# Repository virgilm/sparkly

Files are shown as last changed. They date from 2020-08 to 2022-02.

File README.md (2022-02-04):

# sparkly
**Swimming-Pool Automation Systen with Raspberry Pi + Home Assistant**

#### Disclaimer: THIS IS VERY MUCH A WORK IN PROGRESS, DO NOT EXPECT TO CLONE THIS AND HAVE A WORKING SYSTEM JUST YET!!!



## Overview:

 A cost-effective, easy-to-build, easy-to-use "Swimming Pool Automation System" with top functions to automate, control and monitor (from web) small-medium size swimming pools.

- Automatic filter control (single speed pumps) based on turnover, temperature and energy tariffs. Manual scheduling too. The power relay used needs to be able to withstand the Inductive Load of the Pool Pump motor. 
- 3 sensors:
  - tentacle ([whitebox T3](https://atlas-scientific.com/electrical-isolation/whitebox-t3/)) carrier board with
  - [ph](https://www.atlas-scientific.com/product_pages/circuits/ezo_ph.html), [orp](https://www.atlas-scientific.com/product_pages/circuits/ezo_orp.html), and [RTD](https://atlas-scientific.com/embedded-solutions/ezo-rtd-temperature-circuit/). A custom I2C sensor for HA has been developed.
- and [8 relays](https://sequentmicrosystems.com/collections/home-automation/products/raspberry-pi-relays-stackable-card) (custom HA component for sequent 8 board relay). The relays control :
  - pump on/off
  - muriatic acid injection (to regulate pH)
  - bleach injection (to mantain sanitization level) **or** salt chlorinator control

 The system is intended to monitor and *"automagically"* control most important pool functions and notify to mobile all possible events requiring attention.

 Integrated Node Red for advanced automation functionality.
 
 ## Build system (slightly out of date)
 
 Follow instructions in wiki [howto build a bypass to connect sensors to the pool](https://github.com/segalion/raspipool/wiki/Bypass-for-sensors), [howto connect sensors to the raspberry pi](https://github.com/segalion/raspipool/wiki/Sensors-connection-(DS18B20,-and-EZO-pH-and-ORP)) and [howto connect relays between pumps and raspberry pi](https://github.com/segalion/raspipool/wiki/Connection-of-relays-for-pump-control)
 
 ## Install (really needs work!!! - contributions appreciated)
 0. Install [HAOS](https://www.home-assistant.io/installation/raspberrypi#install-home-assistant-operating-system) in a raspberry pi (3 or 4), and setup wifi connection. (If an advanced user, you can instead install [raspberry pi OS](https://www.raspberrypi.com/software/) + [Home Assistant Core](https://www.home-assistant.io/installation/raspberrypi#install-home-assistant-core))
 *PLEASE DO NOT ASK FOR ASSISTANCE IN INSTALLING HA. It is an overly, unnnecesarly complicated process that should be fully suported by HA.*
 1. Install Node-Red
 2. Copy/clone this repository in the homeassistant conf_dir ( i.e. /home/homeassistant/.homeassistant/ or /mnt/data/supervisor/homeassistant/). The following form allows you to initialize a non-empty directory:

    `git init .`

    `git remote add origin <repository-url>`

    `git pull origin master`

 3. Create a 'secrets.yaml' file under the config_dir directory, containing:

    `latitude: <latitude>`

    `longitude: <longitude>`
    
    `openweathermap_api_key: <key>`
    
    `pushbullet_api_key: <key>`

 4. Start HA and access [http://<sparkly.local>:8123](http://sparkly.local:8123)
 5. Because HA is so wise, you'll need to enable the following integrations via UI (TODO: is there a way to fix this?):
   - Scheduler
   - OpenWeatherMap (you'll need to supply your API key, even if you already set it in your secrets file above)
 6. Change your HA panel configuration to point to your NR installation (check panel_iframe in configuration.yaml) (NR runs at [http://<sparkly.local>:46836](http://sparkly.local:46836))
 7. Connect your node red installation to HA.
 - Generate a [long lived token](https://www.atomicha.com/home-assistant-how-to-generate-long-lived-access-token-part-1/).
 - [Configure HA](https://leonardosmarthomemakers.com/how-to-install-node-red-on-a-raspberry-for-your-home-assistant-smart-home/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) node in Node Red UI

 ## TODO:
 - Water temperature (1-wire [DS18B20 waterproof](https://aliexpress.com/item/32968031204.html))
 - SWC – Salt Water Chlorinator (instead of bleach injections) - in progress
 - Improve calibration (3-point for pH)
 - Heater control
 - Correction of FC-ORP based on CYA (actually only linear correction)
 - Control Variable Speed Motor via RS485
 - Two speed pumps (re-add support)
  
<sub> This is a fork of [raspipool](https://github.com/huehueteotl/raspipool) HEAVILY modified. Thanks to segalion for the original work. Thanks to Hidromaster, Piscidoc, and all DIY enthusiasts from [hablemosdepisicnas](http://www.hablemosdepiscinas.com/foro/viewtopic.php?f=11&t=3906) and [TFP](https://www.troublefreepool.com/threads/raspipool-pool-automation-system-with-raspberry-pi-home-assistant.188410/) forums.</sub>

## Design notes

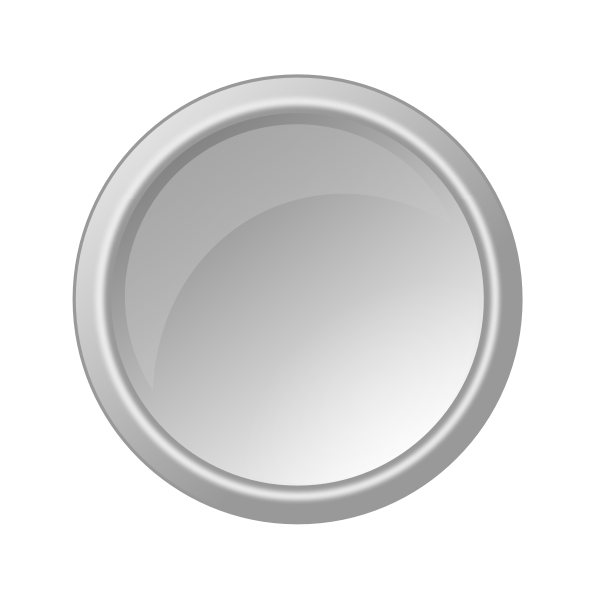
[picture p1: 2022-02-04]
www/glossy-lightgray-button.png

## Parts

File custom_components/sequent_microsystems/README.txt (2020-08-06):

Very basic code to support this board in HA:
https://sequentmicrosystems.com/index.php?route=product/product&product_id=50

Doc explaining the dev process in HA:
https://developers.home-assistant.io/docs/development_index

TODO:
- test I2C communication on init, fail if not working
- implement port logic
- lib8relay 1.0.0 needs to be pushed to PyPi!!
https://developers.home-assistant.io/docs/creating_component_code_review/#4-communication-with-devicesservices
https://jeffknupp.com/blog/2013/08/16/open-sourcing-a-python-project-the-right-way/
Meanwhile, to use it in dev:
https://developers.home-assistant.io/docs/creating_integration_manifest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
- extend this to other devices/input devices too. I can help.

References:
- good example:
https://github.com/home-assistant/core/tree/dev/homeassistant/components/raspihats
- the end result should live here:
https://github.com/home-assistant/core/tree/dev/homeassistant/components

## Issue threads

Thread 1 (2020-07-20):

Issue with flow template

virgilm, 2020-07-20:
Curious if this happens to other people too.

Hass logs:
> 020-07-19 22:01:32 ERROR (MainThread) [homeassistant.components.template.sensor] Could not render template Remain cycles: UndefinedError: 'str object' has no attribute 'minute'

This seems to be because the following line in flow.yaml:
>           {% set nextcycle = strptime(states('sensor.cycle_pool'),'%H:%M').hour + strptime(states('sensor.cycle_pool'),'%H:%M').minute|int/60 %}

sensor.cycle_pool seems to be a string and not a date, or the template seems to think so. It seems that strptime implementation is broken honestly.

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

This seems similar to:
https://community.home-assistant.io/t/convert-string-to-time/37303/2

Closed 2020-07-21.

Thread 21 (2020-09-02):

enity in non-numeric error

AhmedElsafi, 2020-09-02:
Hello,
I am trying to run the raspipool application. I am getting a message for entity is non-numeric for the ph,orp and the pool temperature.   I wonder if you could help me with that
Regards,

virgilm, 2020-09-02:
Did you build the hardware according to the diagrams? Those errors in general indicate you are not getting any readings from your sensors. If you did, check with the command line python shell provided by Atlas Scientific that all your sensors are working in I2C mode and reading data.

docsparks, 2020-09-10:
i had this issue with segalions atlas code and found that i didn't configure my ec probe to give me a reading with a decimal or comma and the code wasn't able to handle it.   forgot which line in the code it was but that was it.

AhmedElsafi, 2020-09-14:
Thanks for the response. Will try that.

AhmedElsafi, 2020-10-19:
Thanks. I went back to it and did the configuration to I2C.

I have another question for you have an early rev that is based on one- wire temperature sensor.

I followed the original BOM

AhmedElsafi, 2020-10-19:
Thanks

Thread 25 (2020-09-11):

calibration only for i2c devices?

docsparks, 2020-09-11:
it looks like the Calibration code is only fitted for i2c device mode,  I'm still new to python and GitHub.   you've updated segalions atlas code quite a bit.   any chances to help me improve calibration for sensors on serialport via USB atlas ezo device? thank you

virgilm, 2020-09-11:
My sensors are I2C, I can't even connect them via serial, as I don't have a carrier board. Calibration clearly needs some work. If you want to give it a try, all you need to do is replace the I2C commands with equivalent serial commands, the logic still stands. You can find those [here](https://atlas-scientific.com/files/oem_pH_datasheet.pdf); serial calibration starts at page 19. pH is the trickiest one, my code only does midpoint calibration for now.

docsparks, 2020-09-15:
Sorry for the delay.    My issue isnt so much the process of calibration, as much as it is creating commands within the python script.    I have already used my sensors for a length of time within windows and understand the commands to do different things, my setback here is my lack of python programming context and homeassistants abilities..

I see that the atlas integration already does mostly what I want, if i wanted to for example, change the temperature for the ph probe, id have to send a command including the current water temperature to the atlas ph sensor via the integration.

but the integration only creates a sensor and has the sensor value as its only return to the component.

how would i extend the existing python script to allow the temperature be set?

I imagine (using hassio/homeassistant OS on a rpi) that i cant open access to the usb port thats already in use by the atlas component, from a custom python script?  or can i?  ill make an attempt at coding this myself today but im still sure that some changes to the origin sensor.py can be fitted to allow input commands, ie set temperature of water.

any help is appreciated, thanks!

virgilm, 2020-09-15:
Oh, I understand. I'm quite new to HA too, I don't know of a way to modify a sensor in such a way - maybe there is one. I'm sure we could implement some other HA entity (e.g. check https://developers.home-assistant.io/docs/dev_101_services) to perform some output functions. The sample code [here](https://www.atlas-scientific.com/files/pi_sample_code.pdf) has an example of python with UART mode.

docsparks, 2020-09-16:
After spending the day yesterday attempting to learn what I could, this is where i got..

segalion had originally started trying to make the code allow parameters for settings, via service.  Found in
https://github.com/segalion/raspipool/blob/master/custom_components/atlas_scientific/__init__.py

I went through numerous custom components I have, as well as info from https://developers.home-assistant.io/docs/dev_101_services and for the limited time i had yesterday, couldnt get anywhere.

I have yet to fully follow the instructions set out with the custom service docs but I still have yet to see in other custom components how the service code could even interact with the python coding in the sensor.py.

I dont have any knowledge with python but have years of programming experience in .net and some java.  I may post on the homeassistant forums.

I hope this helps you make any progress

virgilm, 2020-09-16:
Sorry, I'm not going to spend time on this, as I don't even have a way to test this out, but the only way I can think of at least at this point would be to have a separate entity (not the sensor) that could run the calibration. From what I can gather, extending a sensor does not have a way to add a 'calibrate' method to it. You could do something similar to what I did, which is to run a shell script (scripts.yaml), which in turn calls a python routine. Unfortunately, the python scripts in HA are quite useless from my perspective, as no imports are allowed: https://www.home-assistant.io/integrations/python_script/

docsparks, 2020-09-16:
Thanks again for your contributions to the original code.   It does help.  I have linked to your repo in my question on the home assistant forums.
[https://community.home-assistant.io/t/adding-input-parameters-to-a-custom-component-that-is-only-a-sensor/227281](url)

danielegger1, 2022-01-30:
Not sure where the best place is to contact you, but this might be ok, have you had any luck at implementing the Ezo Pumps with I2C?
Tentacle T3 works without issues?
Bit afraid before buying everything
Thanks in advance

virgilm, 2022-01-30:
T3 works without any issues (but it's a bit expensive for what it is). I have a pump too, but I did not try it out yet. I see no reason for it not to work as expected. I have a bunch of code written for this project, I will push it when I get a chance... way too many things to do, and my pump is an industrial 240V one right now. It should be a matter of just adding to the custom component and adding a switch.

danielegger1, 2022-01-31:
Thanks for your fast reply :)
i just figured out that going through the wifi kit https://www.robesol.nl/en/wi-fi-pool-kit-bare-bones.html might be the easiest way
But I can try Raspipool with that also, just need to manually wire it instead of going through Tentacle.
What do you think about that unit?
Really looking forward to your updated code, I am always happy that people like you are sharing their hard work for stupid users like me :)

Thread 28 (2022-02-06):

GREAT WORK

bbombek, 2022-02-06:
So I have struggled with this build for one year. It seems to be very hard....
And HA is constantly changing. Now the new version doesnt support UART?? Is that a problem?
Anyway i am again stuck.
I see that
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

Also the readme i got stuck at

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

I dont know how how to do no. 6 and 7.
and also i got now two red nodes??

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

And I still dont get any readings from EZo circuits. I Dont know how to enable i2C mode....
and also
what is this?
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

what is sparkly local i dont understans??
PLEASE HELP

virgilm, 2022-02-06:
To set EZO sensors to I2C mode, you can follow [this](https://www.instructables.com/UART-AND-I2C-MODE-SWITCHING-FOR-ATLAS-SCIENTIFIC-E/) tutorial. My version does not support UART mode, you would have to make it work if you really wanted to (the code is there, but commented out). I highly recommend using I2C mode though, it is easier to use and more reliable.

HA is indeed constantly changing (and not for the better IMO). I assume you installed the supervised version of HA, seeing the screenshots - and that is OK. Steps 6 & 7 are irrelevant to you, NR is running and connected to HA apparently, and the second NR entry is useless - just ignore it or remove it from your configuration file.

As I mentioned in the readme, the installation is very much a work in progress and I use HA Core, where some if this stuff is more complicated - but it runs much better on my RPi Zero W 2. I'm actually happy you made it that far, if you can contribute back with Install steps for HA Supervised, that would be nice.

Finally, my installation is called sparkly.local instead of homeassistant.local, so you already have that last point (Start HA and access) working :)

bbombek, 2022-02-06:
OK KUULL
Getting there!
So I enabled I2C mode manually on the EZO circuits now there is the Blue Light!
But still no communication with raspberry pi.
I know how to do it in raspbian OS
https://files.atlas-scientific.com/pi_sample_code.pdf
But how to do that in HA OS??
I found this should i do it?
https://www.home-assistant.io/common-tasks/os/#enable-i2c
I will gladly make a tutorial if I am Successful!

bbombek, 2022-02-06:
So I did this also..
https://www.home-assistant.io/common-tasks/os/#enable-i2c-via-home-assistant-operating-system-terminal
And nothing from the pH sensor...
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

Should sensors still be connected as segalion did??
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

virgilm, 2022-02-06:
Yeah, that won't work with I2C. So I guess you have a choice to make:
- either figure out how to re-enable serial in sparkly (you should be able to by changing the ph.yaml and orp.yaml (the beginning of the file).
- or figure out how to connect your sensors via I2C. Not sure if that Carter board works in I2C code, I am using the tentacle T3 carrier board.
If you decide to go the I2C route, [this](https://community.home-assistant.io/t/add-on-hassos-i2c-configurator/264167) helped me get I2C running on HA, which makes even the most trivial tasks complicated.

askewdread, 2022-04-10:
awesome updates to the code,

> So I did this also.. https://www.home-assistant.io/common-tasks/os/#enable-i2c-via-home-assistant-operating-system-terminal And nothing from the pH sensor... 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
>
> Should sensors still be connected as segalion did?? 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

have finally got this working after much trial and error, the sensor boards need to be connected as per the pi_sample.pdf file not as per the image in the repo, so RX on both boards need connecting to the SCL pin on the PI and the TX on both boards need to be connected to the SDA pin on the PI

then HA correctly finds them and reads :)

bbombek, 2022-05-27:
Hello I am Back!
Now i finally got the Whitebox T3 carrier board for RPI. Now still nothing in HA no readings from sensors...
What to do. Can someone write a quick tutorial.??
THANK YOU

STELTZ-MANIA, 2022-09-06:
Hi @bbombek, how did you get on or have you quit?

I received my Tentacle T3 today and have hooked up the EZO pH and ORP circuits and it appears to be working.
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

Although there is a weird difference between the 2 pH values being presented which I couldn't be bothered thinking about right now.

I'm happy for us to compare notes if you are still having issues.

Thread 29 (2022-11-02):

Really excellent - a couple of questions

cperricos, 2022-11-02:
hello,
I have recently embarked on my raspipool adventure as a way to learn more about HA, python etc. What you have done is really fantastic and am looking forward to seeing it work in my spa. I have a couple of questions:

1) I modified the switches code to work with a simple four relay hat for the pi using GPIo commands. it seems to work BUT... on the main page, when I switch con the main pump it works fine, but when I switch on acid or chlorine, the relay toggles on/off. I havent connected the sensors yet (waiting for my whitebox T3 to arrive), so is this related to some logic that takes ph/ORP readings and then switches pump back off? It is not the relay connection as when I change the main pump to a different relay that  works fine.

2) would it be possible to change the readings to metric units? if so would I need to change any signficiant formulas?

thank yuo so much for your efforts
Costi

virgilm, 2022-11-02:
1. The acid/chlorine pumps need the main pump to work (as a safeguard). So, you have to turn the main pump on to be able to turn on other pumps.
2. There is a lot of code dealing with that (mostly untested). There is a global setting (called [imperial](https://github.com/virgilm/sparkly/blob/f8f904ab863bcf5b469178458f0962738637283f/packages/raspipool/settings.yaml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)) - when set to false it should use metric units.

cperricos, 2022-11-02:
thank you so much for your quick response!!

Will look for that setting.

Also, I already have an HA instance running in the main house. Have you come across any ways to communicate between the raspipool instance and another instance?

virgilm, 2022-11-09:
I'm not aware of a way to connect to an existing HA instance.

cperricos, 2022-11-27:
Hello,
I have made significant progress since my last post. thanks so much for you excellent work. I have the Atlas IOT sensors running remotely and communicating to raspipool via Mqtt. I can display actual orp, temp and ph on the main dashboard, and have gor the gauge for temperature working too. I cannot seem to get the gauge for orp or ph working though. My question is, do I need to have node red activated and running for the dashboards to work? I haven't managed to install it properly (get 505 gateway error) so didnt  know if that was related.

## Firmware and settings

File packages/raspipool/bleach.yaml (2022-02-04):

sensor:
  - platform: template
    sensors:
      bleach_tank:
        friendly_name: "Bleach tank"
        value_template: "{{ states('input_number.bleach_tank')|round(2)}}"
      bleach_inject:
        friendly_name: "Chlorine injection"
        value_template: "{{ states('input_number.bleach_inject')|round(0)}}"
      bleach_inject_imperial:
        friendly_name: "Chlorine injection"
        value_template: "{{ states('input_number.bleach_inject_imperial')|round(1)}}"
      time_to_inject:
        # time to inject chlorine (in secs)
        # depends on chlorine vs. salt
        value_template: >-
          {% if is_state("input_boolean.salt_system", "on") %}
            "{{ [0 , 60 * 60 * states('input_number.bleach_inject')|float/ states('input_number.chlorine_production')|float ]|max|int }}"
          {% else %}
            "{{ [0 , 60 * states('input_number.bleach_inject')|float/ states('input_number.bleach_speed')|float ]|max|int }}"
          {% endif %}

  - platform: history_stats
    name: bleach_on_last_hour
    entity_id: switch.orp
    state: "on"
    type: time
    end: "{{now().replace(minute=0).replace(second=0)}}"
    duration: 01:00:00

  - platform: history_stats
    name: bleach_on_last_48h
    entity_id: switch.orp
    state: "on"
    type: time
    end: "{{now()}}"
    duration: 48:00:00

input_number:
  bleach_tank:
    min: 0
    max: 76
    step: 1
    unit_of_measurement: "l"
    icon: mdi:blood-bag
    name: Chlorine Tank
  bleach_tank_imperial:
    min: 0
    max: 20
    step: 1
    unit_of_measurement: "gal"
    icon: mdi:blood-bag
    name: Chlorine Tank
  bleach_concentration:
    min: 5
    max: 30
    step: 1
    unit_of_measurement: "%"
    icon: mdi:water-percent
  bleach_speed:
    min: 0
    max: 263
    step: 1
    unit_of_measurement: "ml/min"
    icon: mdi:needle
  bleach_speed_imperial:
    min: 0.1
    max: 100
    step: 0.1
    unit_of_measurement: "gal/day"
    icon: mdi:needle
  notify_bleach_high:
    name: Chlorine Overfeed
    min: 0
    max: 15.2
    step: 0.1
    unit_of_measurement: "l/48h"
    icon: mdi:format-color-fill
  notify_bleach_high_imperial:
    name: Chlorine Overfeed
    min: 0
    max: 4
    step: 0.1
    unit_of_measurement: "gal/48h"
    icon: mdi:format-color-fill
  notify_bleach_tank:
    name: Chlorine Tank Low
    min: 0
    max: 8
    step: 0.1
    unit_of_measurement: "l"
    icon: mdi:flask-empty-outline
  notify_bleach_tank_imperial:
    name: Chlorine Tank Low
    min: 0
    max: 2
    step: 0.1
    unit_of_measurement: "gal"
    icon: mdi:flask-empty-outline
  bleach_inject:
    min: 0
    max: 10000
    step: 1
    unit_of_measurement: "ml"
    icon: mdi:beaker
    mode: box
  bleach_inject_imperial:
    min: 0
    max: 400
    step: 1
    unit_of_measurement: "oz"
    icon: mdi:beaker
    mode: box

automation:
  # Sync Tank Capacity (l vs gal)
  - alias: bleach_sync_1
    trigger:
      - platform: state
        entity_id: input_number.bleach_tank
    condition: []
    action:
      - service: input_number.set_value
        data_template:
          entity_id: input_number.bleach_tank_imperial
          value: "{{(states('input_number.bleach_tank')|float / 3.78541)| round(0) }}"

  - alias: bleach_sync_2
    trigger:
      - platform: state
        entity_id: input_number.bleach_tank_imperial
    condition: []
    action:
      - service: input_number.set_value
        data_template:
          entity_id: input_number.bleach_tank
          value: "{{(states('input_number.bleach_tank_imperial')|float * 3.78541)| round(0) }}"

  # Sync Injection Speed capacity (ml/min vs GPD)
  - alias: bleach_speed_sync_1
    trigger:
      - platform: state
        entity_id: input_number.bleach_speed
    condition: []
    action:
      - service: input_number.set_value
        data_template:
          entity_id: input_number.bleach_speed_imperial
          value: "{{(states('input_number.bleach_speed')|float / 2.6287)| round(1) }}"

  - alias: bleach_speed_sync_2
    trigger:
      - platform: state
        entity_id: input_number.bleach_speed_imperial
    condition: []
    action:
      - service: input_number.set_value
        data_template:
          entity_id: input_number.bleach_speed
          value: "{{(states('input_number.bleach_speed_imperial')|float * 2.6287)| round(1) }}"

  # Sync Injection Speed capacity (ml/min vs GPD)
  - alias: bleach_inj_sync_1
    trigger:
      - platform: state
        entity_id: input_number.bleach_inject
    condition: []
    action:
      - service: input_number.set_value
        data_template:
          entity_id: input_number.bleach_inject_imperial
          value: "{{(states('input_number.bleach_inject')|float * 0.033814)| round(1) }}"
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

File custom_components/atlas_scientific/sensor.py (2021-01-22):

# Under MIT licence
# Release 0.1 (06/08/2019) by segalion at gmail
# ORP & pH tested. DO & EC from datasheets, so possible errors like ORP/OR


import logging
import serial
import io
import fcntl
import string
import time

from homeassistant.helpers.entity import Entity
from homeassistant.const import (
	CONF_NAME, CONF_UNIT_OF_MEASUREMENT, CONF_PORT)
from homeassistant.components.sensor import PLATFORM_SCHEMA
import voluptuous as vol
import homeassistant.helpers.config_validation as cv
from homeassistant.const import TEMP_CELSIUS, TEMP_FAHRENHEIT

_LOGGER = logging.getLogger(__name__)
CONF_OFFSET = 'offset'
CONF_SCALE = 'scale'
# Validation of the user's configuration
PLATFORM_SCHEMA = PLATFORM_SCHEMA.extend({
	vol.Required(CONF_PORT): cv.string,
	vol.Optional(CONF_NAME, default='ezo'): cv.string,
	vol.Optional(CONF_OFFSET, default=0.0): vol.Coerce(float),
	vol.Optional(CONF_SCALE, default=TEMP_CELSIUS): cv.string
})

def setup_platform(hass, config, add_devices, discovery_info=None):
	"""Setup the sensor platform."""
	add_devices([AtlasSensor(
		name=config.get(CONF_NAME),
		port=config.get(CONF_PORT),
		offset=config.get(CONF_OFFSET),
		scale=config.get(CONF_SCALE)
	)])

class AtlasSensor(Entity):
	"""Representation of a Sensor."""
	io_mode = 0					# 0 = serial, 1 = I2C
	long_timeout = 1.5         	# the timeout needed to query readings and calibrations
	short_timeout = .5         	# timeout for regular commands
	default_i2dev = "/dev/i2c-1"    # the default bus for I2C on the newer Raspberry Pis, certain older boards use bus 0
	auto_sleep = 1              # enable auto sleep mode after readings

	def __init__(self, name, port, offset, scale):
		"""Initialize the sensor."""
		self._state = None
		self._name = name
		self._offset = offset
		# try to convert variations of TEMP_CELSIUS, C, ºC, °C to a unique format
		lowercase_scale = scale[-1].lower()
		self._scale = lowercase_scale
		# Identifiers: [ name (from I?), units, icon, auto_sleep ]
		if lowercase_scale == 'f':
			temp_uom = TEMP_FAHRENHEIT
		else:
			# default to CELSIUS
			temp_uom = TEMP_CELSIUS
		temp = ['temperature', temp_uom, 'mdi:coolant-temperature', 1]
		ezos = {"ph": ['ph', 'pH', 'mdi:alpha-h-circle', 1],
			   "orp": ['orp', 'mV', 'mdi:alpha-r-circle', 1],
			   "or": ['orp', 'mV', 'mdi:alpha-r-circle', 1],
			   "do": ['dissolved_oxygen','mV', 'mdi:alpha-x-circle', 0],
			   "d.o.": ['dissolved_oxygen','mV', 'mdi:alpha-x-circle', 0],
			   "ec": ['conductivity', "EC", 'mdi:alpha-c-circle', 0],
			   "rtd": temp}

		_LOGGER.debug("Checking port %s", port)
		self.port = int(port,0)
		if(self.port > 0):
			self.io_mode = 1 # switch to I2C communication
			_LOGGER.info("I2C for Atlas EZO @%02x", self.port)
			self.file_read = io.open(self.default_i2dev, "rb", buffering=0)
			self.file_write = io.open(self.default_i2dev, "wb", buffering=0)

			# initializes I2C to the given port/address
			self.set_i2c_address(self.port)

		else:
			self.io_mode = 0 # serial
			self.port = port
			_LOGGER.info("Serial for Atlas EZO @%s",port)
			self.ser = serial.Serial(port, 9600, timeout=3, write_timeout=3)

			# Reset buffer
			self._read("")
			# Get Status
			status = self._read("Status")
			# Set response ON
			ok = self._read("*OK,1")
			ok += self._read("RESPONSE,1")
			# Set continuos  mode OFF
			c = self._read("C,0")

		# Get kind of EZO
		self._ezo_dev = None
		for i in range(5):
			ezo = self._read("I")
			_LOGGER.debug("I -> check: "+ezo)
			if ezo is not None:
				ezo = ezo.lower().split(',')
				if len(ezo)>2 and ezo[1] in ezos:
					self._ezo_dev = ezos[ezo[1]][0]
					self._ezo_uom = ezos[ezo[1]][1]
					self._ezo_icon = ezos[ezo[1]][2]
					self.auto_sleep = ezos[ezo[1]][3]
					self._ezo_fwversion = ezo[2]
					self._name += ("_" + self._ezo_dev)
					_LOGGER.info("Atlas EZO '%s' version %s detected" % (self._ezo_dev, self._ezo_fwversion ) )
					break
		if self._ezo_dev.lower() == 'temperature':
			# set default temperature scale
			self.i2c_write("S,{:s}".format(self._scale))
		if self._ezo_dev is None:
			_LOGGER.error("Atlas EZO device error or unsupported: "+ezo )

	def set_i2c_address(self, addr):
		# set the I2C communications to the slave specified by the address
		# The commands for I2C dev using the ioctl functions are specified in
		# the i2c-dev.h file from i2c-tools
		I2C_SLAVE = 0x703
		fcntl.ioctl(self.file_read, I2C_SLAVE, addr)
		fcntl.ioctl(self.file_write, I2C_SLAVE, addr)

	@property
	def name(self):
		"""Return the name of the sensor."""
		# return "Atlas Scientific"
		return self._name

	@property
	def device_class(self):
		"""Return the device class of the sensor."""
		return self._ezo_dev

	@property
	def icon(self):
		"""Return the icon of the sensor."""
		return self._ezo_icon

	@property
	def fw_version(self):
		"""Return the firmware version of the sensor."""
		return self._ezo_fwversion

	@property
	def state(self):
		"""Return the state of the sensor."""
		return self._state

	@property
	def unit_of_measurement(self):
		"""Return the unit of measurement."""
		return self._ezo_uom

	def i2c_write(self, cmd):
		# appends the null character and sends the string over I2C
		_LOGGER.debug("I2C write cmd: " + cmd)
		cmd += "\00"
		cmd = cmd.encode()
		return self.file_write.write(cmd)

	def i2c_read(self, num_of_bytes=31):
		# reads a specified number of bytes from I2C, then parses and displays the result
		res = self.file_read.read(num_of_bytes)         # read from the board
		response = list(filter(lambda x: x != '\x00', res))     # remove the null characters to get the response
		if response[0] == 1:             # if the response isn't an error
			# change MSB to 0 for all received characters except the first and get a list of characters
			char_list = map(lambda x: chr(x & ~0x80), list(response[1:]))
			# NOTE: having to change the MSB to 0 is a glitch in the raspberry pi, and you shouldn't have to do this!
			return ''.join(char_list)     # convert the char list to a string and returns it
		else:
			_LOGGER.error("I2C read error: " + str(response[0]))
			return ''

	def _read(self,command="R",terminator="\r*OK\r"):
		line = ""
		if self.io_mode == 0:
			self.ser.write((command + "\r").encode())
			for i in range(50):
				line += self.ser.read().decode()
				if ( line[0]=="*" and line[-1]=="\r") or terminator in line: break
			line.replace(terminator,"")
		else:
			self.i2c_write(command)
			# the read and calibration commands require a longer timeout
			if((command.upper().startswith("R")) or
				(command.upper().startswith("CAL"))):
				time.sleep(self.long_timeout)
			elif command.upper().startswith("SLEEP"):
				return "sleep mode"
			else:
				time.sleep(self.short_timeout)
			line = self.i2c_read().rstrip('\x00')
		return line
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

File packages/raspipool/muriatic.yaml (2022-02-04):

sensor:
  - platform: template
    sensors:
      muriatic_tank:
        friendly_name: "Acid tank"
        value_template: "{{ states('input_number.muriatic_tank')|round(2)}}"
      muriatic_inject:
        friendly_name: "Acid injection"
        value_template: "{{ states('input_number.muriatic_inject')|round(0)}}"
      muriatic_inject_imperial:
        friendly_name: "Acid injection"
        value_template: "{{ states('input_number.muriatic_inject_imperial')|round(1)}}"

  - platform: history_stats
    name: muriatic_on_last_hour
    entity_id: switch.ph
    state: "on"
    type: time
    end: "{{now().replace(minute=0).replace(second=0)}}"
    duration: 01:00:00

  - platform: history_stats
    name: muriatic_on_last_48h
    entity_id: switch.ph
    state: "on"
    type: time
    end: "{{now()}}"
    duration: 48:00:00

input_number:
  muriatic_tank:
    min: 0
    max: 76
    step: 1
    unit_of_measurement: "l"
    icon: mdi:blood-bag
    name: Acid Tank
  muriatic_tank_imperial:
    min: 0
    max: 20
    step: 1
    unit_of_measurement: "gal"
    icon: mdi:blood-bag
    name: Acid Tank
  muriatic_concentration:
    min: 5
    max: 30
    step: 1
    unit_of_measurement: "%"
    icon: mdi:water-percent
  muriatic_speed:
    min: 0
    max: 66
    step: 1
    unit_of_measurement: "ml/min"
    icon: mdi:needle
  muriatic_speed_imperial:
    min: 0.1
    max: 25
    step: 0.1
    unit_of_measurement: "gal/day"
    icon: mdi:needle
  notify_muriatic_high:
    name: Acid Overfeed
    min: 0
    max: 100
    step: 0.1
    unit_of_measurement: "l/48h"
    icon: mdi:format-color-fill
  notify_muriatic_high_imperial:
    name: Acid Overfeed
    min: 0
    max: 25
    step: 0.1
    unit_of_measurement: "gal/48h"
    icon: mdi:format-color-fill
  notify_muriatic_tank:
    name: Acid Tank Low
    min: 0
    max: 8
    step: 0.1
    unit_of_measurement: "l"
    icon: mdi:flask-empty-outline
  notify_muriatic_tank_imperial:
    name: Acid Tank Low
    min: 0
    max: 2
    step: 0.1
    unit_of_measurement: "gal"
    icon: mdi:flask-empty-outline
  muriatic_inject:
    min: 0
    max: 10000
    step: 1
    unit_of_measurement: "ml"
    icon: mdi:beaker
    mode: box
  muriatic_inject_imperial:
    min: 0
    max: 400
    step: 1
    unit_of_measurement: "oz"
    icon: mdi:beaker
    mode: box

automation:
  # Sync Tank Capacity (l vs gal)
  - alias: acid_sync_1
    trigger:
      - platform: state
        entity_id: input_number.muriatic_tank
    condition: []
    action:
      - service: input_number.set_value
        data_template:
          entity_id: input_number.muriatic_tank_imperial
          value: "{{(states('input_number.muriatic_tank')|float / 3.78541)| round(0) }}"

  - alias: acid_sync_2
    trigger:
      - platform: state
        entity_id: input_number.muriatic_tank_imperial
    condition: []
    action:
      - service: input_number.set_value
        data_template:
          entity_id: input_number.muriatic_tank
          value: "{{(states('input_number.muriatic_tank_imperial')|float * 3.78541)| round(0) }}"

  # Sync Injection Speed capacity (ml/min vs GPD)
  - alias: acid_speed_sync_1
    trigger:
      - platform: state
        entity_id: input_number.muriatic_speed
    condition: []
    action:
      - service: input_number.set_value
        data_template:
          entity_id: input_number.muriatic_speed_imperial
          value: "{{(states('input_number.muriatic_speed')|float / 2.6287)| round(1) }}"

  - alias: acid_speed_sync_2
    trigger:
      - platform: state
        entity_id: input_number.muriatic_speed_imperial
    condition: []
    action:
      - service: input_number.set_value
        data_template:
          entity_id: input_number.muriatic_speed
          value: "{{(states('input_number.muriatic_speed_imperial')|float * 2.6287)| round(1) }}"

  # Sync Injection quantity (ml vs. oz)
  - alias: acid_inj_sync_1
    trigger:
      - platform: state
        entity_id: input_number.muriatic_inject
    condition: []
    action:
      - service: input_number.set_value
        data_template:
          entity_id: input_number.muriatic_inject_imperial
          value: "{{(states('input_number.muriatic_inject')|float * 0.033814)| round(1) }}"

  - alias: acid_inj_sync_2
    trigger:
      - platform: state
        entity_id: input_number.muriatic_inject_imperial
    condition: []
    action:
      - service: input_number.set_value
        data_template:
          entity_id: input_number.muriatic_inject
          value: "{{(states('input_number.muriatic_inject_imperial')|float / 0.033814)| round(0) }}"
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

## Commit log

2020-05-22 Add i2c support, Atlas RTD sensor, Fritzing schema. Lots of WIP!
    [RaspiPool Extra Parts V2.fzz]
2020-07-20 Fix ph and orp mean values.
    It seems that mean does not work (anymore?). The default value is
    the mean value, so simply putting ph and orp does seem to work.
    Also, these I believe were wrong anyway:
    ph.yaml:
    value_template:
    '{{state_attr("sensor.ph", "standard_deviation") > 0.1}}'
    orp.yaml:
    value_template:
    '{{state_attr("sensor.orp", "standard_deviation") > 20 }}'
    [muriatic.yaml]
2020-07-29 Support for sensor calibration.
    Added the following:
    - shell command to run python script (could not make python work
    directly in HA - lame!)
    - python script for generic calibration (ph, orp, temp=rtd)
    - python script usage: calibrate.py <device> <target>
    - scripts.yaml to invoke the shell service with proper params
    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
2020-08-03 Various bugfixes.
    - use off for pump state instead on none
    - use RTD sensor from Atlas Scientific
    - enable sleep mode for RTD sensor
    - use 30 sec read intervals
    [sensor.py]
2020-08-05 Move to Fahrenheit only.
    Too many issues, needs localization.
    [sensor.py]
2020-08-06 Bugfixes in calibration.
    - wait for calibration
    - more debugs
    - strip null characters
    - add some tolerance (0.02) - might be not enough
    - and more...
2020-08-06 Add relay controls.
2020-08-13 Cosmetic changes
    - capitalization
    - UI auto-arrange
    - calibration values
    - notifications in the app too
2020-08-26 Fixing temperature calculation
    All internal calculations use degrees centigrades
    Only the frontend shows Fahrenheit now.
2020-08-26 Use gallons for pool capacity
    global input_boolean for imperial units.
2020-09-05 Adding a flow sensor
    - on GPIO14
    - other cosmetic, minor bugfixes
    Flow sensor is not used yet, except to show state.
    [bleach.yaml, muriatic.yaml, switches.yaml]
2020-09-10 Many changes.
    - temp fixes (C/F)
    - UI optimizations
    - verify automation for temp, ph, orp
    - moved automation to each respective file
    [bleach.yaml, muriatic.yaml]
2020-09-10 Improve/tweak configuration.
    Adding temp sensor to homekit.
2020-09-11 More bugfixes.
    - fully checked the pH, temperature and ORP workflows
    [bleach.yaml, muriatic.yaml, settings.yaml]
2020-10-07 Rework automation
    Also add a switch to disable the flow switch if one is not present.
    [settings.yaml]
2021-01-22 Trying to use scheduler component.
    Lots of issues, limitations of HA.
    Needs upgrade of both HA and scehduler component.
    Schedules seem to get lost...
    [bleach.yaml, muriatic.yaml]
2022-02-04 State of Sparkly as of Feb 2022.
    A code dump from my internal branch.
    History can be found there.
    Many many changes, mostly works. Installation is a PITA.
    HA is making most automation of the installation more and more
    difficult. This is an ISSUE.
    Node red now used for complicated automation, that was not possible
    with HA. appdaemon was an option, but NR is friendlier.
    Integration is a problem, need solution for preserving NR flows on
    a new install w/o having to recreate a long term token.
    [advanced.yaml, bleach.yaml]
2025-07-17 Skip onboarding, fix NR to run on container.
    [settings.js]
2025-07-17 HA errors, stale entries.
    [settings.yaml]
